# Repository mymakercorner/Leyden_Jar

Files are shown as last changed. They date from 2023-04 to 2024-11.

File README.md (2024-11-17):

# The Leyden Jar

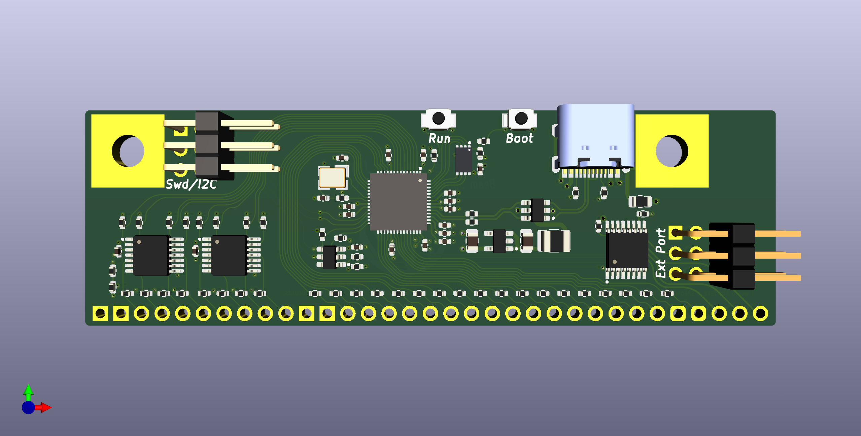
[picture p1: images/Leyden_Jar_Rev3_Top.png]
Leyden Jar render front

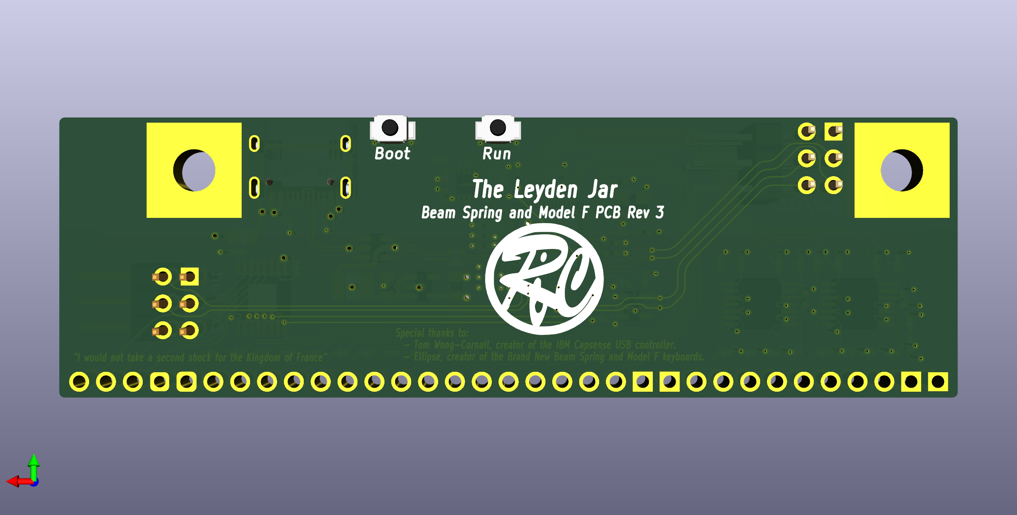
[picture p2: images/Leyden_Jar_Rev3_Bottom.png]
Leyden Jar render back


The [Leyden Jar](https://en.wikipedia.org/wiki/Leyden_jar) is a modernized controller PCB for the Brand New Model F and Beam Spring keyboards.
The name is taken from the first ever (crude) capacitor ever invented.

Please have a look at the Keebtalk [here](https://www.keebtalk.com/t/the-leyden-jar-a-tentative-pcb-replacement-for-the-brand-new-model-f-keyboards/17489/1) for more details on the development process.
This repository is the central hub of several other repositories and links that may be need to build or dowloand software firmware and tools, see chapter below for more details.

## Useful links

### Leyden Jar Diagnostic Tool

The **Leyden Jar Diagnostic Tool** is an application meant to perform troubleshooting and inspection on Leyden Jar controller firmwares.

Github link: https://github.com/mymakercorner/Leyden_Jar_Diagnostic_Tool

Windows binaries are also available from this **Leyden Jar Diagnostic Tool** Github page. 

### QMK/VIAL Firmware Source Code

Firmware source code is available in my forked vial-qmk repository in the **leyden_jar** branch.

Github link: https://github.com/mymakercorner/vial-qmk/tree/leyden_jar

Prebuilt firmwares are also available from this forked vial-qmk Github page.

## How the project started

It was in April 2022 when Ellipse of Model F Labs asked in Geekhack and Deskthority forums if someone was up to make a new RP2040 based controller PCB that could replace the Xwhatsit controller that it was using in it's Brand New Model F and Beam Spring keyboards.  

I never worked on capacitive sensing technologies and never used RP2040 MCUs before. 
Also the amound of work looked quite big as a both a new PCB design and firmware code had to be made from the ground up.
But this is something that crossed my mind for quite a long time before and was excited to take this challenge.

The Leyden Jar PCB is the result of one year of work trying to fullfill this little dream of mine!

## Project status

Several revisions have been designed.

Revision 1 has been used to do a first battle test of the design on real boards.
My own Brand New Model F77 keyboard has first been used to validate the PCB design and the firmware.  
Later some controllers have been sent to Ellipse for further testing/development on one of it's Brand New Beam Spring Full Size Round 2 keyboards. 

Newer revisions modifications are rather minor. But while revision 1 was already working great I wanted to tidy up things a bit and also Ellipse had a few requests that were nice to have implemented.  

### Note
At the time of this writing the firmware code has been adapted from revision 1 without any validation and the revision 2 PCB is still not manufactured and tested.

## Licence

In order to give tribute to Tom Wong-Cornall, the inventor of the IBM Capsense USB keyboard controller, with the exceptions noted below, everything is provided with the same GPLv3 licence he used at the time.

### Exception for some 3D models

Two 3D model files, taken from SnapEDA website, that are using the [Creative Commons Attribution-ShareAlike 4.0 International License (CC BY-SA)](https://creativecommons.org/licenses/by-sa/4.0/)  with the [Design Exception 1.0 licence](https://www.snapeda.com/about/FAQ/#designexception):
* B3U-3000P--3DModel-STEP-56544.STEP
* TYPE-C-31-M-12--3DModel-STEP-56544.STEP

## Use at your own risks

This PCB design and software are provided for free and I am not paid for this work.  
Although it worked for my Model F77 and one of Ellipse's Beam Spring keyboard it may not for you or even worse can render your keyboard unusable.   
By using this material you agree that I will not be liable for any problems you may have.

## Features

### Hardware

* 4 layers PCB designed using Kicad 6.x.
* RP2040 MCU.
* 2MB external QSPI XIP flash memory.
* USB C receptacle.
* ESD protection of both VBUS and D+/D- lines,
* Overcurrent protection with a resettable fuse.
* EMI shielding using a ferrite bead.
* All matrix IO pins rugged with 1K current limit resistors.
* Status leds driven by an I2C IO expander chip.
* 3X2 header for:
    * Solenoid driver.
    * Future PS2 AT daugherboard.
* 3x2 header for:   
    * SWD debugging.
    * External I2C connection. 

### Software

* QMK VIAL firmware (VIA compatible by providing vial.json file).
* Solenoid support.
* 3 QMK layers support (can be much more if user want, we have little to no memory constraints).
* Custom USB raw HID protocol support for basic monitoring/debugging using an external tool. 
* Early support for following keyboards:
    * Brand New Model F77 (tested on my own F77).
    * Brand New Model F62 (untested).
    * Brand New Beam Spring Full Size Round 2 (tested by Ellipse).
    * Brand New Beam Spring SSK (untested, matrix definition may be totally wrong).

## Repository content

### pcb/leyden_jar_controller
Contains Kicad 6.x project files.

### production_files/leyden_jar_controller/bom
Contains an HTML interactive BOM, very handy for people wanting to solder the components themselves.

### production_files/leyden_jar_controller/jlcpcb
Contains everything needed to manufacture and assemble the controller at JLCPCB.  
The 4 buttons and 2 3x2 headers are not listed in the BOM.

### images 
Images content, mostly for this repository documentation.

## Revision History

### Revision 1

First version, not available in this repository.

### Revision 2

* Added support for 2 additional columns.
* Now uses only one I2C bus.
* Removed external I2C EEPROM chip (keyboard state is saved in QSPI flash memory). 
* Solenoid now driven by RP2040 IO pins (was done through I2C IO expander before).
* Added early future support to PS/2 daughterboard using existing solenoid connector.
* Routing improvements.
### Revision 3

* Last free pin of the solenoid connector now outputs 3.3V.
* Top left connector rework:
    * Now a 3X2 connector.
    * Left 3 pins are ground and SWD pins.
    * Right 3 pins are 3.3V and I2C pins (to drive potential future I2C devices). 
* Run/Bootsel buttons rework:
    * added 2 additional buttoms on the bottom of the PCB.
    * footprints reworked to easily short pads with a flat screwdriver.
    * buttons not populated by default.
    * B3U-1000P variants (top press version) listed in project.
    * still comatible with B3U-3000P variants (side press version).
* Routing improvements.
## Comparison with existing controllers

To my knowledge all existing controllers we see nowadays in our Model F or Beam Spring keyboards are derivatives of 2014 Tom Wong-Cornall work for the Xwhatsit controller PCB.  
As a result they share the same capacitive detection principle and the Leyden Jar controller is no different in that regard.
Tom Wong-Cornall explained it in great details in this [link](https://static.wongcornall.com/ibm-capsense-usb-web/ibm-capsense-usb.html).

The first obvious difference is the use of a modern RP2040 MCU instead of the old good Atmega 32U2.  
It is a cheap MCU and still widely available during the current component shortage period.  
But it is the features that it was giving that resulted in a significantly different way to implement the well known capacitive detection principle.

1. PIO feature  
The timing of pulsing the matrix colums and reading the rows are crutial to have consistent/reliable results.  
On Xwhatsit accurate timings are ensured by writing all this critical code part in Atmega assembler.  
With the Leyden Jar PIO is used instead with no CPU intervention during the whole matrix scanning process.  
We can safely manage much tighter timings using PIO than using the CPU, this allowed me to have significantly more aggressive/shorter timings and reduce the time it takes to make a full matrix scan: it takes 40us to strobe a single column for a total of 640us to scan 16 columns.  

2. Available memory  
There is 264KB of RAM available on RP2040 vs 1KB on Atmega32U2.  
External flash is usually 2MB vs 32KB.  
No more need to count how many memory bytes you have left when you're coding the firmware, you'll always have memory available when you'll need it; this makes firmware programming significantly easier and opens up new possibilities.

3. Available GPIOs  
There are 30 available on RP2040 vs 22 on Atmega32U2.  
As a result we have enough IO pins to directly drive the matrix scanning system, removing the need of the IO expander chips we find in existing controllers.  
The Leyden Jar can drive up to 18 columns instead of 16 on current controllers, making big keyboards designs like F122 less of a challenge.  
All 30 GPIO pins are used in this design, nothing is lost ;)

4. Working voltage  
It is 3.3V on RP2040 vs 5V on Atmega32U2.  
Old controllers like Atmegas were very often working at 5V to give them good noise immunity.  
On moderm ARM controllers working at lower voltages, noise becomes a problem that needs to be taken care off. If you add the fact that pulsing columns at 3.3V will give smaller voltage spikes than doing that with 5V, minimizing noise is even more important for this particular case.  
This is why the Leyden Jar PCB is a 4 layers design, with all critical traces all on the top layer with no vias, a solid ground place on the layer just below and the last 2 layers containing the power planes and non critical traces.  
Traces are also curved. While it aestetically pleasing it is also done to limit reflection problems when pulsing the columns (curved traces are often used in high frequency applications PCBs). 

5. I2C usage  
This protocol is used instead of SPI to minimize IO pin usage, only 2 GPIO pins are used to drive both a DAC chip (for the voltage reference) and a IO expander chip (mostly used for driving the 3 LEDs).

## PS2 AT to USB daughterboard PCB

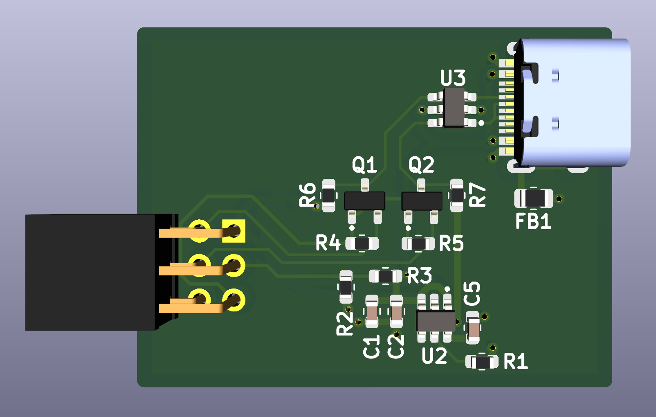
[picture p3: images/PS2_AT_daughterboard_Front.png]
PS2 AT Daughterboard front

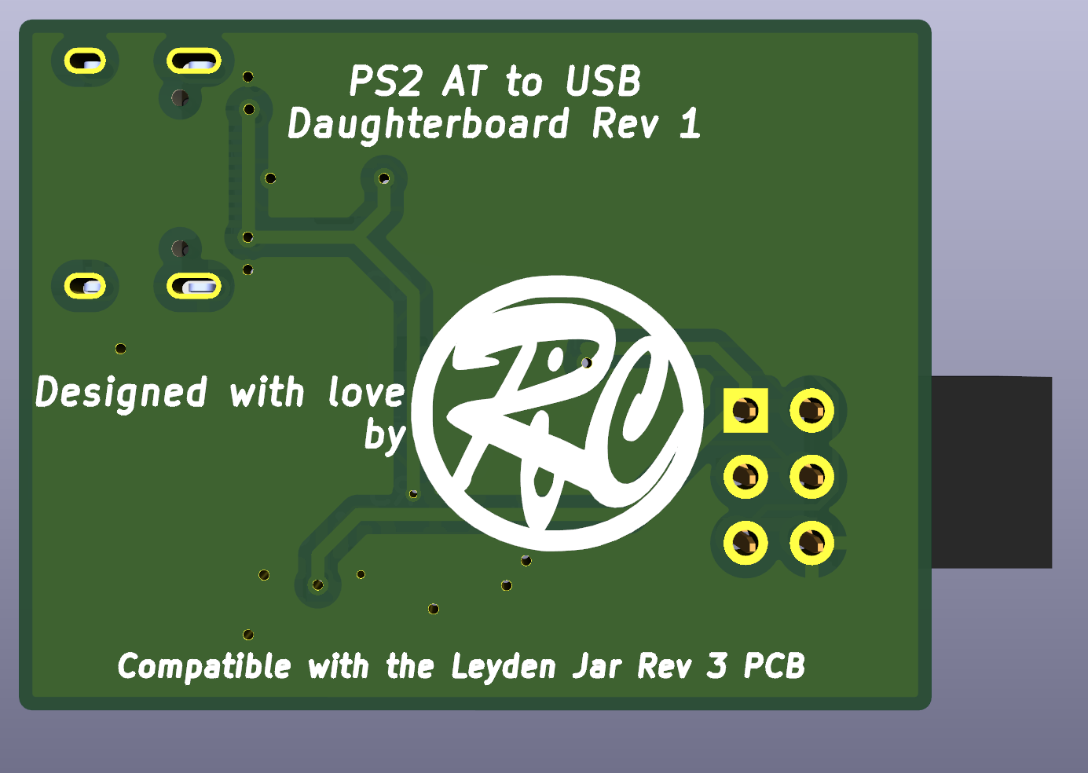
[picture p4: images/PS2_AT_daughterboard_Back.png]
PS2 AT Daughterboard back


This new sister project is a daughterboard that connects into the IO expander of the Leyden Jar controller.  
This extension aims in the future to provide PS2 AT compatibility.  
As the same IO expander port is also used for the solenoid connector you will not be able to use both solenoid and PS2 AT extensions at the same time.

### pcb/ps2_at_daughterboard
Contains Kicad 6.x project files.
### production_files/ps2_at_daughterboard
Contains everything needed to manufacture and assemble the board at JLCPCB.  

**WARNING!!!**  
This project is in it's very early stage.  
We have yet to manufacture PCBs, test them and write software for them.

## Special thanks

If people as still able nowadays to type on a Model F or Beam Spring keyboard, either old good or brand new, it is thanks to the hard work and dedication of several people of this great keyboard community.

### Tom Wong-Cornall
The first who designed a controller replacement for the IBM Model F and Beam Spring keyboards, the IBM capsense USB controller (Xwhatsit). Most if not all existing controllers are based on it's original design.  

### Ellipse of Model F Labs
He manufactured the Brand New Model F and Beam Spring keyboards, it is always a great pleasure to type on my Model F77 board.

### Wcass
He made many variants of the original XWhatsit controller and a lot of switch plate PCB designs for Ellipse.

### Pandrew
He also made variants of the XWhatsit and Solenoid controllers and worked on the QMK/VIA port of original Tom Wong-Cornall firmware, improved it and maintained it for all those years.

For all those people and many I forgot to mention, **thank you!**

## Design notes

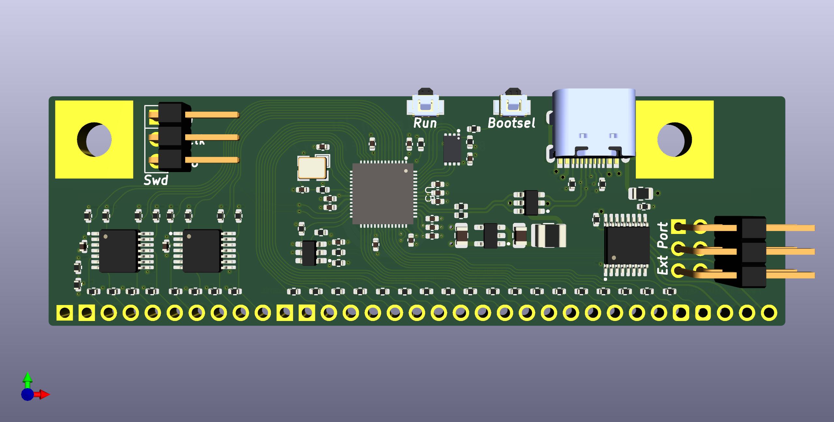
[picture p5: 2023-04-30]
images/Leyden_Jar_Rev2_Front.png

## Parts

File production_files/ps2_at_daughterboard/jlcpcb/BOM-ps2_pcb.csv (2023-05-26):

Comment | Designator | Footprint | LCSC
2K | R2 | Resistor_603 | C100291
1K | R1,R3 | Resistor_603 | C11702
CBW201209U121T | FB1 | R_805 | C139186
100n | C2 | Capacitor_603 | C1525
USB_C_Receptacle_USB2.0 | J2 | USB_C_Receptacle_HRO_TYPE-C-31-M-12 | C165948
10K | R4,R5,R6,R7 | Resistor_603 | C25744
BSS138 | Q1,Q2 | SOT-23 | C2874697
1u | C1,C5 | Capacitor_603 | C52923
MIC2009A-1YM6 | U2 | SOT-23-6 | C625657
USBLC6-2SC6 | U3 | SOT-23-6 | C7519

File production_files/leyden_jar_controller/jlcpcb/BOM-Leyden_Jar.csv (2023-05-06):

Comment | Designator | Footprint | LCSC
MCP4716A0T-E/CH | U10 | SOT-23-6 | C110057
1000 | R10,R11,R14,R15,R16,R18,R20,R21,R22,R23,R24,R26,R28,R29,R30,R31,R32,R34,R4,R46,R47,R48,R49,R5 | R_0402_1005Metric | C11702
CBW201209U121T | FB1 | R_0805_2012Metric | C139186
PCA9557PW,118 | U8 | TSSOP-16_4.4x5mm_P0.65mm | C141380
ADP122AUJZ-3.3-R7 | U4 | TSOT-23-5 | C143910
100n | C1,C10,C11,C12,C13,C19,C20,C21,C4,C5,C6,C7,C8,C9 | C_0402_1005Metric | C1525
30p | C14,C15 | C_0402_1005Metric | C1570
USB_C_Receptacle_USB2.0 | J1 | USB_C_Receptacle_HRO_TYPE-C-31-M-12 | C165948
4.7u | C16,C17 | C_0805_2012Metric | C1779
RP2040 | U5 | QFN-56-RP2040 | C2040
27 | R2,R3 | R_0402_1005Metric | C25100
10k | R1,R12,R17,R25,R33,R36,R38,R40,R41,R6,R8 | R_0402_1005Metric | C25744
47k | R13,R19,R27,R35,R37,R39,R50,R7,R9 | R_0402_1005Metric | C25792
4.7k | R42 | R_0402_1005Metric | C25900
5.1k | R43,R44 | R_0402_1005Metric | C25905
7.5k | R45 | R_0402_1005Metric | C25918
LMV339 | U2,U6 | TSSOP-14_4.4x5mm_P0.65mm | C273648
W25Q16JVUXIQ | U1 | USON8_3x2mm | C2843335
1u | C2,C3 | C_0402_1005Metric | C52923
mSMD110-16V | F1 | Fuse_1210_3225Metric | C70102
USBLC6-2SC6 | U3 | SOT-23-6 | C7519
12MHz | Y1 | Crystal_SMD_3225-4Pin_3.2x2.5mm | C9002

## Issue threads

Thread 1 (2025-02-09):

Texas Instruments LMV339IPW(R) discontinued, complete PCBA at JLC no longer possible

moldimolt, 2025-02-09:
Hello. I wanted to report that it seems LMV339IPW(R) is being discontinued, and is already down to 1 unit remaining at JLC, preventing PCBA of this component as each Leyden Jar controller uses 2 units.

* https://jlcpcb.com/partdetail/TexasInstruments-LMV339IPWR/C273648
* https://www.ti.com/product/LMV339/part-details/LMV339IPW

Texas Instruments recommends [LM339LVPWR](https://www.ti.com/product/LM339LV/part-details/LM339LVPWR) as a `drop-in replacement with upgraded functionality to the compared device`. Could you confirm this part will work for the Leyden Jar controller's intended use-case, and update the BOM if so?

Thank you!

mymakercorner, 2025-02-10:
Hello Mordi,The lmv339 is a pretty standard chip design across several manufacturers, not only Texas Instruments have one but also OnSemi and many others.As such they should be electrically compatible, now there is the question of the times (or speed) of each brand.Let me take time to read the datasheet of both reference to have a better picture.Keep in mind that either if my answer is positive there is always a risk that the replacement does not give the same result as the current one.Best Regards,RicoLe 9 févr. 2025 23:46, Mordi ***@***.***> a écrit :
Hello. I wanted to report that it seems LMV339IPW(R) is being discontinued, and is already down to 1 unit remaining at JLC, preventing PCBA of this component as each Leyden Jar controller uses 2 units.
https://jlcpcb.com/partdetail/TexasInstruments-LMV339IPWR/C273648https://www.ti.com/product/LMV339/part-details/LMV339IPW
Texas Instruments recommends LM339LVPWR as a drop-in replacement with upgraded functionality to the compared device. Could you confirm this part will work for the Leyden Jar controller's intended use-case, and update the BOM if so?
Thank you!

—Reply to this email directly, view it on GitHub, or unsubscribe.You are receiving this because you are subscribed to this thread.Message ID: ***@***.***>

mymakercorner, 2025-02-12:
Le 12.02.2025 01:25, Mordi a écrit :

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

I had a quick look at the datasheets, the new reference looks nearly
identical to the one I am using right now.

Tell me if it works for you !

On what board will you plan to use those controllers ?

Best Regards,

Rico

Links:
------
[1]
https://github.com/mymakercorner/Leyden_Jar/issues/1#issuecomment-2652356077
[2]
https://github.com/notifications/unsubscribe-auth/AWVSIHFZMXLHH7EWMAZNOPT2PKIHJAVCNFSM6AAAAABWZJJOMGVHI2DSMVQWIX3LMV43OSLTON2WKQ3PNVWWK3TUHMZDMNJSGM2TMMBXG4
--=_0a7aef15abfe419038d120522d17ce7f
Content-Transfer-Encoding: quoted-printable
Content-Type: text/html; charset=UTF-8

<html><head><meta http-equiv=3D"Content-Type" content=3D"text/html; charset=
=3DUTF-8" /></head><body style=3D'font-size: 10pt'>
<p id=3D"reply-intro">Le 12.02.2025 01:25, Mordi a &eacute;crit&nbsp;:</p>
<blockquote type=3D"cite" style=3D"padding: 0 0.4em; border-left: #1010ff 2=
px solid; margin: 0">
<div id=3D"replybody1">
<p><br /></p>
<p dir=3D"auto">Thanks! I have just assembled 5 units using Texas Instrumen=
t's recommended replacement part LM339LVPWR, I will report back if this is =
a functional replacement once the units arrive from JLC.</p>
<p style=3D"font-size: small; -webkit-text-size-adjust: none; color: #666;"=
>&mdash;<br />Reply to this email directly, <a href=3D"https://github.com/m=
ymakercorner/Leyden_Jar/issues/1#issuecomment-2652356077" target=3D"_blank"=
 rel=3D"noopener noreferrer">view it on GitHub</a>, or <a href=3D"https://g=
ithub.com/notifications/unsubscribe-auth/AWVSIHFZMXLHH7EWMAZNOPT2PKIHJAVCNF=
SM6AAAAABWZJJOMGVHI2DSMVQWIX3LMV43OSLTON2WKQ3PNVWWK3TUHMZDMNJSGM2TMMBXG4" t=
arget=3D"_blank" rel=3D"noopener noreferrer">unsubscribe</a>.<br />You are =
receiving this because you commented.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<span style=3D"color: transparent; font-size: 0; display: non=
e; visibility: hidden; overflow: hidden; opacity: 0; width: 0; height: 0; m=
ax-width: 0; max-height: 0; mso-hide: all;">Message ID: <span>&lt;mymakerco=
rner/Leyden_Jar/issues/1/2652356077</span><span>@</span><span>github</span>=
<span>.</span><span>com&gt;</span></span></p>
</div>
</blockquote>
<p><br /></p>
<p>I had a quick look at the datasheets, the new reference looks nearly ide=
ntical to the one I am using right now.</p>
<p>Tell me if it works for you !</p>
<p><br /></p>
<p>On what board will you plan to use those controllers ?</p>
<p><br /></p>
<p>Best Regards,</p>
<p><br /></p>
<p>Rico</p>
<p><br /></p>
<p><br /></p>

</body></html>

--=_0a7aef15abfe419038d120522d17ce7f--

moldimolt, 2025-02-15:
Hello Rico,

I will be using them on:
1. An original Model F122
2. 3x Model M122s with [ViviLazuli's MtF PCB](https://github.com/ViviLazuli/mtf-capacitive)

I will let you know if they work, thanks!

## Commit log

2023-04-30 [feature] Initial Leyden Jar Revision 2 design delivery.
    [BOM-Leyden_Jar.csv, Leyden_Jar.kicad_pcb, Leyden_Jar.kicad_sch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]
2023-05-06 [feature] Revision 3 design delivery.
    [BOM-Leyden_Jar.csv, Leyden_Jar.kicad_pcb, Leyden_Jar.kicad_sch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]
2023-05-26 [feature] Added PS2 AT daughterboard
    [BOM-Leyden_Jar.csv, BOM-ps2_pcb.csv, Leyden_Jar.kicad_pcb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]
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2026-10-26 [feature] V2 connector and component placement test fit on the Rev 3 outline.
    RP2350B, 4x4 mm 8 MB flash and 1.1 V core LDO replace the RP2040 parts.
    PCA9557, top-side buttons and the 18 column resistors are removed.
    New headers: Qwiic/SWD (JST SH, bottom side), split, display, expansion,
    encoder, and a 2x4 Ext Port. Placement only, nothing is rerouted yet.
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2026-10-26 [feature] V2 schematic: RP2350B, new power path and new connectors.
    RP2350B replaces the RP2040; PCA9557, column resistors, polyfuse and
    top-side buttons are removed. Adds the AP22653 USB power switch,
    TLV74311 1.1 V core LDO, TPS7A2033 3.3 V LDO, 8 MB flash, ABM8 crystal,
    2x4 Ext Port with USB D+/D-, Qwiic, SWD, split, display, encoder and
    expansion headers. New project symbols: AP22653W6, TLV743xxPDBV,
    MCP4716xxx-xCH.
2026-10-26 [cleanup] V2 schematic: bypass capacitors grouped per RP2350B supply pin.
    Decoupling caps are grouped by supply pin (VREG_VIN + VREG_AVDD, 1V1 bulk,
    DVDD, IOVDD, QSPI_IOVDD, USB_OTP_VDD, ADC_AVDD) in the MCU bypass block.
    The 33R + 4.7uF VREG_AVDD filter is removed: with the internal regulator
    disabled, VREG_AVDD joins VREG_VIN on 3V3 per RP2350 datasheet Figure 24.
2026-10-26 [cleanup] V2 schematic: single TVS on the split data line.
    The USBLC6-2SC6 on the split header is replaced by one ESD9B3.3ST5G TVS
    on UART_DATA. The split 5V stays on +5V after the AP22653, whose bulk
    capacitance absorbs ESD on that pin.
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2026-10-26 [feature] V2: single-row J7 breakout header and Rev 3 SWD/I2C header J3 back.
    Connector placement feedback:
    - J10 (expansion), J7 (split) and J8 (TFT display) merged into one 1x17 header J7 so a ribbon cable can be
    soldered in one row. Pins 1-6 expansion + GND, 7-9 split (+5V, GND, UART_DATA), 10-17 ST7789 module order.
    On the board: y 1.4, pin 1 x 12.761 to pin 17 x 53.401, centered between H1's pad and the USB-C body.
    - JST SH J5 (Qwiic) and J6 (SWD) reverted to Rev 3's 2x3 SWD/I2C header J3 (same pinout and footprint), placed
    at Rev 3's x but lower to clear J7 (origin 11.55, 5.08).
2026-10-26 [feature] V2: top-side RUN/BOOT buttons back, J3 and J9 aligned.
    - SW3/SW4 (top side, B3U-1000P) re-added in parallel with SW1 (RUN) and SW2 (USB_BOOT), as in Rev 3.
    All four buttons vertical, left of the USB-C below the J7 row, top and bottom pairs at the same XY:
    RUN (51.70, 5.6), BOOT (55.00, 5.6), pitch 3.3 mm (was 3.7).
    - J3 moved so its pin 1 sits under J7 pin 1 (x 12.761).
    - J9 moved so its pin 5 sits above J2 pin 1 (x 1.60); the comparator block (U2, U6 and their resistors and
    capacitors) moved 0.2 mm right with it to keep the same clearances.
    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
2026-10-28 [cleanup] V2 schematic: everything on the 1.27 mm grid, vertical power symbols.
2026-10-28 [cleanup] V2 schematic: title block V2 rev 1, J3/J4/JP1 drawing fixes.
2026-10-28 [cleanup] V2 schematic: block frames and layout rework, comparator fields point to TI LMV339IPWR.
2026-10-30 [feature] V2 PCB synced from the schematic, Rev 3 tracks and vias removed.
2026-10-30 [feature] V2: power chain (AP22653, 3V3 and 1V1 LDOs) and USB path placed.
2026-10-30 [feature] V2: last parts placed (JP1, D1, I2C pull-ups, encoder RC), old Rev 3 silkscreen labels removed.
2026-10-30 [fix] V2: C22 moved clear of the H2 mounting-hole pad (0.16 mm to 0.24 mm).
2026-10-30 [cleanup] V2 BOM cost and RP2350 flash compatibility reports (2026-10-28), KiCad project local settings.
2026-10-30 [feature] V2: USB 27R series resistors moved next to U3, C22 cleared of U8.
2026-10-30 [feature] V2: MCU cluster moved 1 mm down to widen the band below J7.
2026-10-31 [wip] Manually placed components to optimize layout.
    Also routed Col and Row traces to check that they fit.
2026-10-31 [feature] V2: flash QSPI traces routed, QSPI_SCLK back in the Signal netclass.
2026-11-01 [wip] Reroute +5V around U5 and add 6 GND vias in its exposed pad.
2026-11-01 [wip] Clear B.Cu signals from under the USB pair and add B.Cu to the GND fill.
2026-11-01 [bugfix] Footprint type mismatches on J1 and Y1.
    J1 stays SMD with its 4 shield legs marked as mechanical pads, Y1's crystal
    footprint is now SMD. Board DRC has no errors left.
2026-11-01 [cleanup] Footprint updates, LCSC fields back on the board and BOM/position exclusions.
    Footprints updated from library and silkscreen fields hidden. LCSC fields
    restored from the schematic. JP1, H1-H3, J2, J3, J4, J7, J9 and SW1-SW4
    excluded from BOM and position files. DRC: no errors, schematic parity clean.
2026-11-01 [cleanup] Project copies of the expansion headers without silkscreen, renamed by function, and DNP.
    J3 I2cSwd_2x03, J4 SolenoidPs2_2x04, J7 SpiDispPlusExp_1x17 and J9 Encoder_1x05 now
    use footprints in Leyden_Jar.pretty with no silkscreen graphics and BOM/position
    exclusions in the library. The "Ext Port" silkscreen text is removed.
2026-11-01 [cleanup] Project copies of the U1, U4, U5, U7 and U8 footprints, square GND pads on J7/J9.
    U1 (SOIC-8), U5 (QFN-80) and U4/U7 (SOT-23-5) now use copies in Leyden_Jar.pretty, and U8
    uses the existing Leyden_Jar:SOT-23-6. J7 pads 6/8 and J9 pad 5 (GND) are square with
    45 degree thermal spokes; EXP_GP32 (B.Cu) and +5V (In2.Cu) rerouted so both lower spokes
    reach the GND zone. DRC clean.
2026-11-01 [fix] Missing 3D models: RP2350B model from Raspberry Pi, crystal model, KiCad 10 model paths.
    U5 uses rpi_rp2350b.step, extracted from Raspberry Pi's RP2350B minimal KiCad design
    (MIT, licence file next to it, credited in the README). Y1 gets KiCad's 3225 crystal
    model. Project footprints that pointed to ${KICAD6_3DMODEL_DIR} .wrl files (undefined in
    KiCad 10) now use ${KICAD10_3DMODEL_DIR} .step models. DRC clean.
2026-11-01 [cleanup] V2 board silkscreen text and title block.
    Bottom silkscreen now reads "The Leyden Jar V2" / "Beam Spring and Model F PCB Rev 1" and the
    PCB title block says "Leyden Jar controller PCB V2", rev 1. DRC clean.
2026-11-01 [cleanup] Track fragments, stale netclass patterns and the USB path note.
    Cleanup Tracks & Vias merged/removed 105 redundant segments (no via removed). Netclass
    patterns: dropped /~{QSPI_SCLK} and /EXP_GP48, Net-(R41-Pad2) is now Net-(U10-VOUT), and
    /TFT_CS, /TFT_DC, /TFT_RST join Signal. CLAUDE.md describes the USB path as routed.
    DRC clean, 0 unconnected.
2026-11-01 [feature] Power netclasses and VBUS rerouted at 0.5 mm on outer layers with paired vias.
2026-11-01 [feature] Display VCC on 3V3 only (JP1 removed) and +5V rerouted on outer layers.
2026-11-01 [feature] +1V1 rerouted at 0.5 mm on In2 and 0.4 mm on outer layers with paired vias, USB pair reshaped around it.
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2026-11-02 [feature] +3V3 rerouted at 0.4 mm on outer layers and 0.5 mm on In2, with a separate sense feed from C17.
2026-11-02 [feature] V_REF and ROW_PULLUP filter caps added (C18 4.7 nF, C30 22 nF) with matched time constants.
2026-11-02 [feature] 33 R series resistors on the display SPI clock and data lines (R14, R15).
2026-11-03 [feature] U5 decoupling GND stubs widened to 0.3 mm with 0.3 mm vias, own vias for C12/C28 and U5 pins 62/65.
    R2/R3 moved 0.1 mm left with the USB pair vias and the In2 pair end reshaped; C2 fed straight from the +3V3 rail.
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2026-11-03 [cleanup] TFT J7 stubs in the Signal netclass and rerouted at 0.125 mm, dead TFT_VCC pattern removed.
2026-11-03 [feature] GND stitching vias at the USB and display SPI layer changes.
2026-11-03 [cleanup] Sense-chain, encoder and TVS GND stubs widened, R45 +3V3 feed narrowed to 0.3 mm.
2026-11-03 [cleanup] 0402 pad necks, U5 pin 60 neck, UART_DATA at 0.125 mm in the Signal netclass.
2026-11-04 [fix] CLAUDE.md LED and J7 expansion pin order matched to the PCB.
2026-11-07 [feature] J7 grown to 1x18 with a second serial port on GP32 and its ESD diode D2.
2026-11-08 [cleanup] Silk-free project copies of the 0402/0805 passives and SOD-923, Fab text pass.
    The 71 passives (R/C 0402, C 0805, FB1) and D1/D2 now use Leyden_Jar: copies of the KiCad 10
    stock footprints with their F.SilkS graphics removed. Silkscreen is left only on the project
    footprints with a pin-1 mark and the logo. Fab reference/value text resized and repositioned.
    DRC clean.
2026-11-08 [feature] Back silkscreen art generator (draft), buttons and J9 moved to make room for it.
    pcb/leyden_jar_controller/art/backsilk.py builds the B.SilkS pin legends from the board geometry
    and renders a bottom-view preview with a silk-to-copper clearance check. Drafted so far: J7 groups,
    the J3 SWD / I2C card, J2 groups and the J9 encoder legend; not yet on the board.
    SW1-SW4 moved down to y 6.1 so the TFT bracket fits under CS/BLK, J9 moved up 0.5 mm to
    (1.6, 10.765) to free the J9/J2 GND corner. DRC clean.
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2026-11-09 [cleanup] Unused project footprints and 3D models removed from the library.
    Removed footprints not used by the V2 board or schematic: D_SOD-123, SWD_Header, TSSOP-8,
    SpiDispPlusExp_1x17 (never used) and the Rev 3-only QFN-56-RP2040, TSOT-23-5, TSSOP-16, USON8_3x2mm,
    Rico_Logo and SPST_B3U-3000P (still available on main), plus the USON8_3x2 and B3U-3000P STEP models
    only they used. README licence section updated (SnapEDA list, Barlow Condensed font under SIL OFL),
    CLAUDE.md layout lists the back-silk generator. DRC clean.
2026-11-09 [feature] J2 back silkscreen groups show their pin order.
    Pin 1 of J2 is on the right in bottom view, so the old "R0-7" / "C0-15" tabs read backwards. Each group now
    has its end-pin indices standing on the bracket above those pins, with a short name tab in the middle:
    2 LED 0 | 17 16 | 15 COL 0 | GND | 7 ROW 0 | GND (checked against the J2 pad nets).
    Art re-imported on B.SilkS and verified against art/backsilk_board.json; DRC clean.
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2026-11-09 [cleanup] Front matrix trace cleanup.
    F.Cu only: ROW0-7 rerouted between the comparators and U5 (slightly shorter, up to 0.4 mm on ROW4),
    COL6-7 and COL10-17 reshaped in their fan-out to J2 (same lengths). All 0.125 mm; vias, footprints and
    art unchanged. DRC clean, schematic parity 0.
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2026-11-11 [feature] Back layer routing tightened, USB pair cleared from PS2_ENABLE.
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2026-11-11 [feature] Sense chain coupling reduced: U6 block shifted, V_REF loops replaced by In2 vias, A_ROW7 GND guard.
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
